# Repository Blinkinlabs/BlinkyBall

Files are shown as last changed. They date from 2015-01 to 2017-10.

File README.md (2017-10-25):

# Circuit and code for a heartbeat bouncy ball
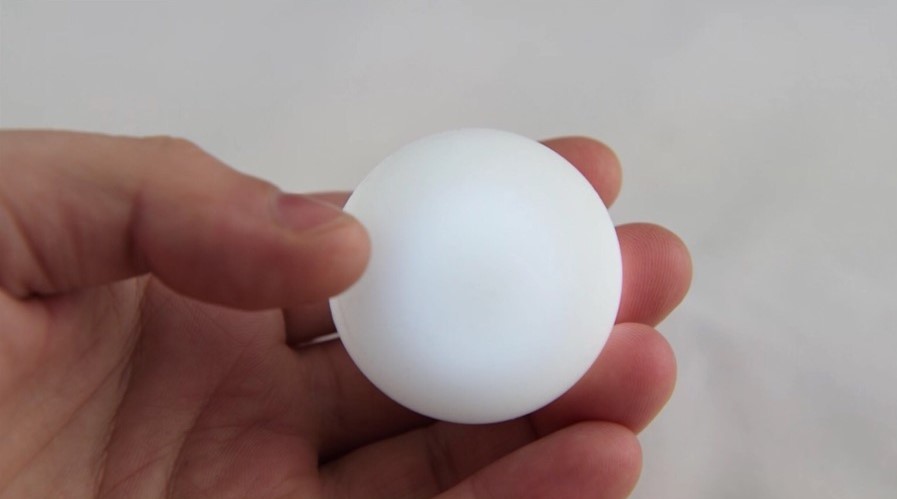
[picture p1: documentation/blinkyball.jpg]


## License

This design, including the software and hardware, is licensed under the MIT license.

## PCB Design

The PCB design is made in Cadsoft Eagle 7.1 (http://www.cadsoftusa.com/download-eagle/).
The free version should be fine for opening and editing the design.

It's based on the Atmel ATTINY85, though an ATTINY45 or ATTINY25 would probably also work.

## Firmware

The firmware is written against avr-gcc.

### Toolchain setup for OS X

Install XCode and command line tools. Version 6.1.1 was used for development, but this should
not be critical. The method for enabling the command line tools seems to be a moving target,
one set of instructions is here (https://developer.apple.com/library/ios/technotes/tn2339/_index.html).

Install CrossPack for AVR (http://www.obdev.at/products/crosspack/download.html). Version
CrossPack-AVR 20130212 was used for development. Most likey this code is not version-sensitive.

### Compiling

Once the toolchain is configured, this should be as simple as:

  make
  
### Uploading firmware

An AVR ISP is required to upload code. The Makefile is configured to use a USBTinyISP
(https://learn.adafruit.com/usbtinyisp), however it would be trivial to use a different
one, or even an Arduino to upload the code.

Solder the 6 ICSP test points on the board (use Eagle to inspect the pinout- the board design
is a moving target), then an automatic upload should work:

  make install

A test jig can also be built to make code upload possible without soldering.

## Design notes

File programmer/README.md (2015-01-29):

# Test Programmer for RasPi

This is a test system for Raspberry Pi. To use it, you'll first need to install avrdude:

	sudo apt-get install avrdude

Make sure that this repository is downloaded to /home/pi/BlinkyBall.

Then add it to init.d:

	cd ~pi/BlinkyBall
	cp programmer/blinkyball-programmer /etc/init.d
	update-rc.d blinkyball-programmer defaults	

# Pinout

This is the pinout for the board. Note that the pin numbers listed are Pi pins, not GPIO

Button should be connected from pin 3 to GND

LED anode to +3.3V
Red LED cathode to pin 22
Green LED cathode to pin 24
Blue LED cathode to pin 26

# Usage

Once the script is installed, it should start automatically at boot. Press the button to start the upload procedure. The light should turn blue while testing, then red if the upload failed or green if it passed.

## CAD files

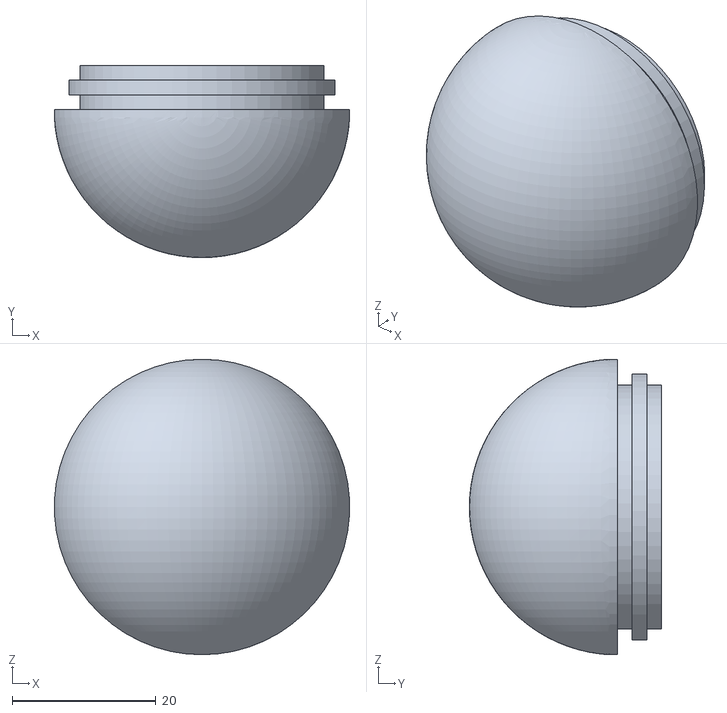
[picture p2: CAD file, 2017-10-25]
releases/case bottom.STL
41.1 x 26.8 x 41.1

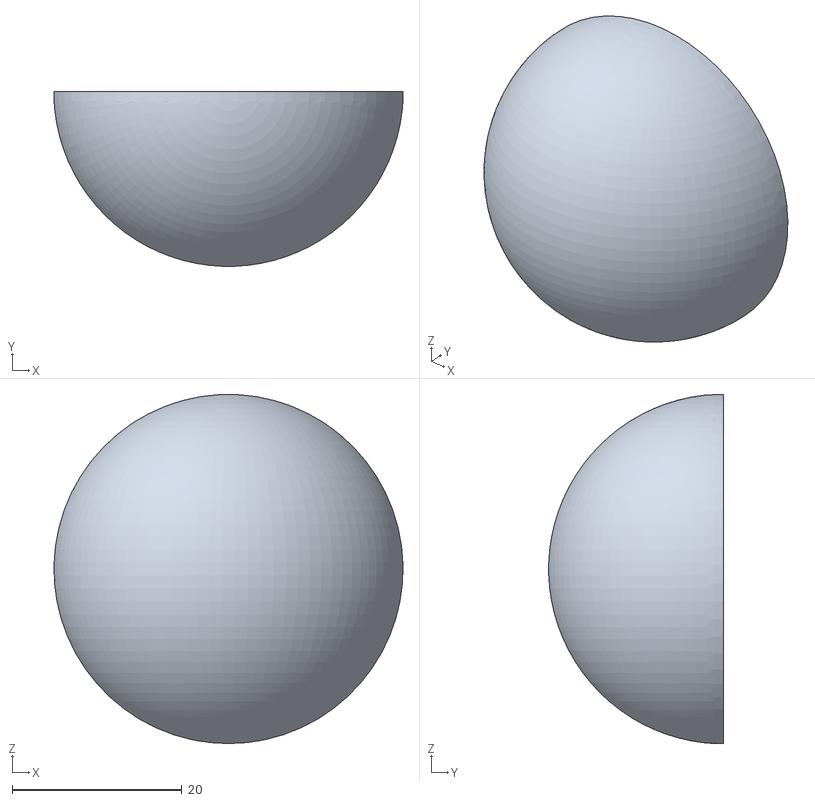
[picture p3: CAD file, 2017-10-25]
releases/case top.STL
41.1 x 20.6 x 41.1

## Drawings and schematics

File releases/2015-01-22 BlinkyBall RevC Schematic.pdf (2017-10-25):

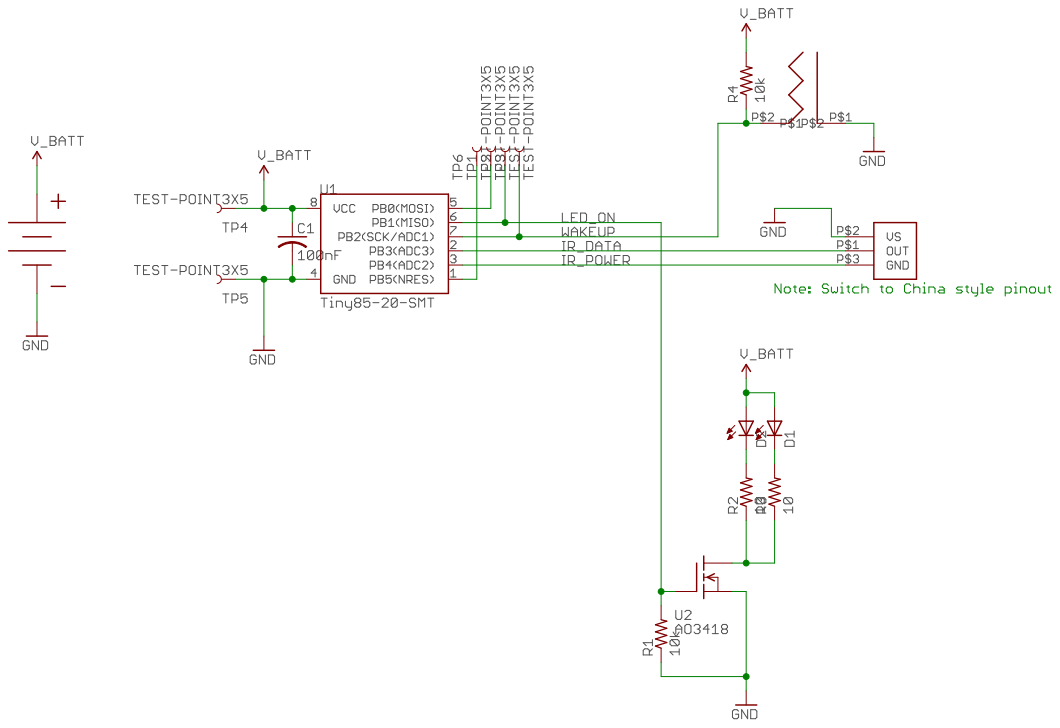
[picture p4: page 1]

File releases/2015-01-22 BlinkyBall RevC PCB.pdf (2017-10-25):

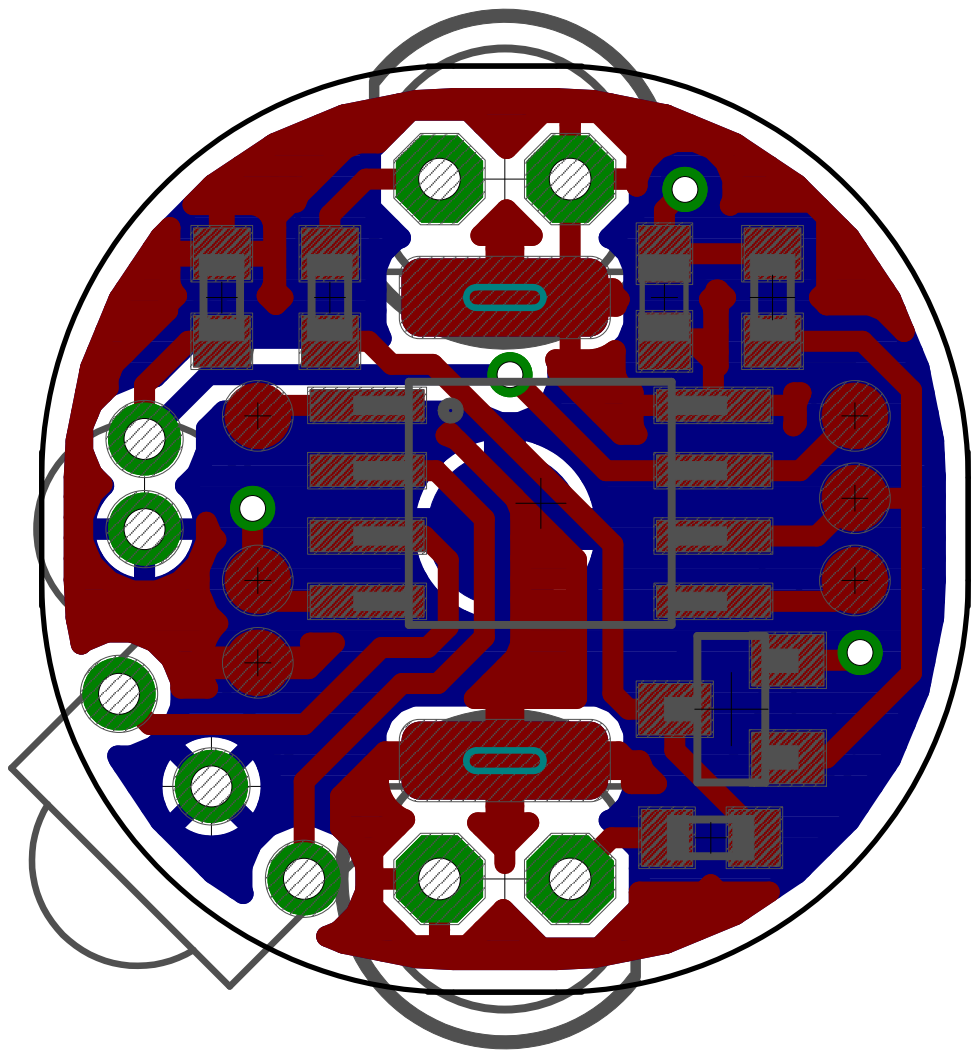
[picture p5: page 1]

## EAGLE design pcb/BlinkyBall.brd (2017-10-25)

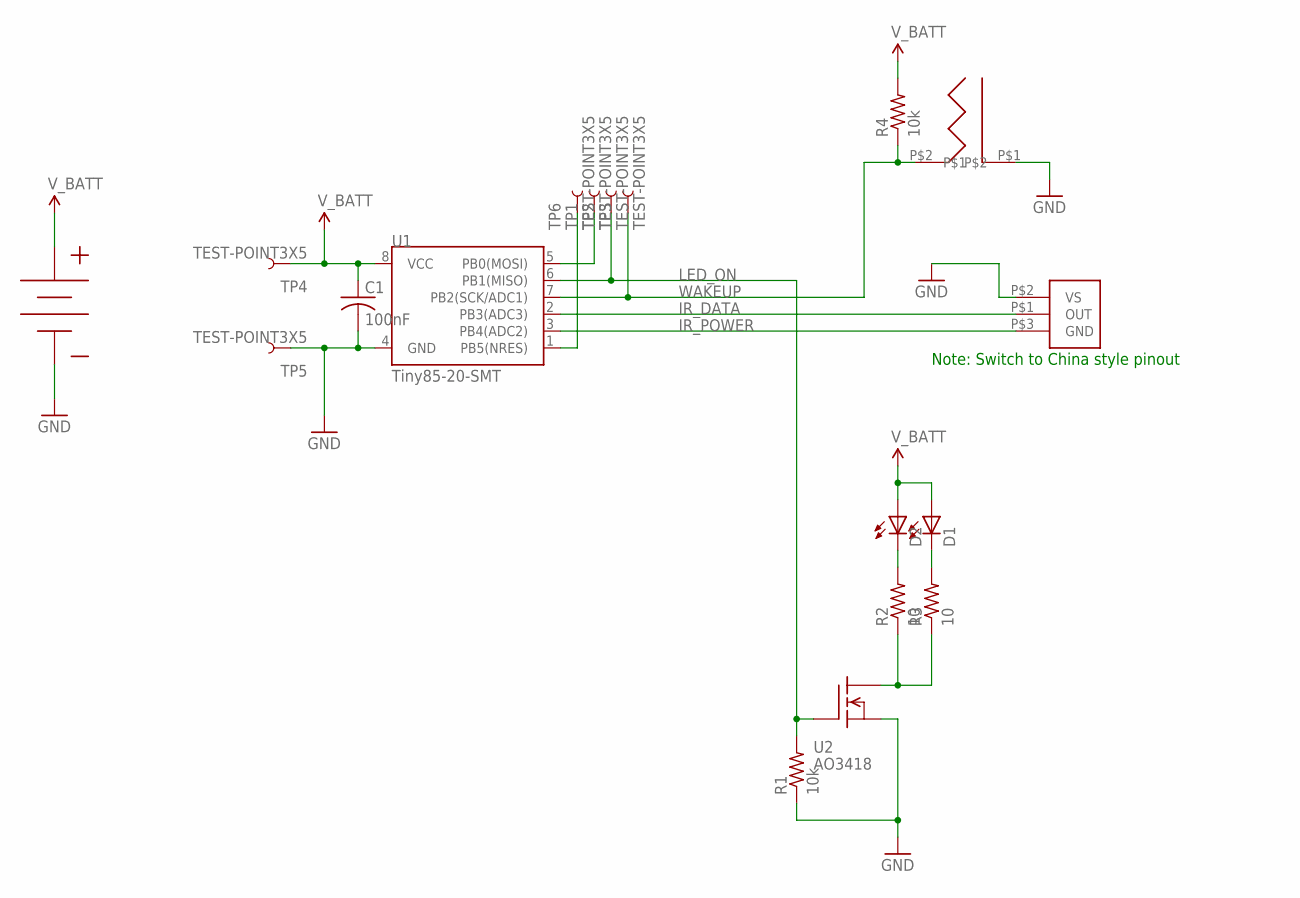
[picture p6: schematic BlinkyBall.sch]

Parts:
C1: 100nF; C0603
D1, D2: LED5MM
J1: SW-18015P
J2: BATTERY_BUTTON_CELLAG3; BATTERY_COVER_AG3
R1, R4: 10k; R0603
R2, R3: 10; R0603
TP1, TP2, TP3, TP4, TP5, TP6: TEST-POINT3X5; PAD.03X.05
U1: Tiny85-20-SMT; SO08-EIAJ
U2: AO3418; SOT23
U3: TSOP321

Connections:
GND: C1.2, J1.P$1, J2.-, R1.1, TP5.P$1, U1.4 (GND), U2.2 (S), U3.P$2 (VS)
IR_DATA: U1.2 (PB3(ADC3)), U3.P$1 (OUT)
IR_POWER: U1.3 (PB4(ADC2)), U3.P$3 (GND)
LED_ON: R1.2, TP2.P$1, U1.6 (PB1(MISO)), U2.1 (G)
unnamed: D2.K (C), R2.2
unnamed: D1.K (C), R3.2
unnamed: R2.1, R3.1, U2.3 (D)
RESET: TP6.P$1, U1.1 (PB5(NRES))
V_BATT: C1.1, D1.A, D2.A, J2.+1 (+), J2.+2 (+), J2.+3 (+), J2.+4 (+), R4.2, TP4.P$1, U1.8 (VCC)
WAKEUP: J1.P$2, R4.1, TP3.P$1, U1.7 (PB2(SCK/ADC1))
YYYYY: TP1.P$1, U1.5 (PB0(MOSI))

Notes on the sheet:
Note: Switch to China style pinout

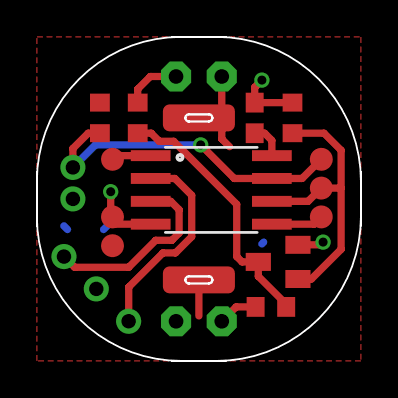
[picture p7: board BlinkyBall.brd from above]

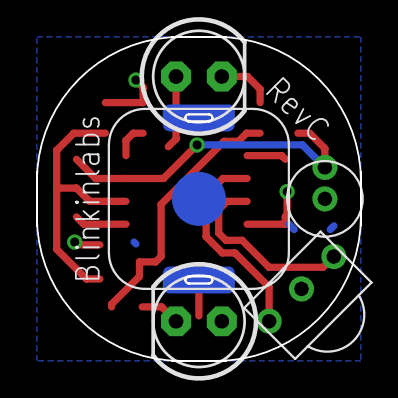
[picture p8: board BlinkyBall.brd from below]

Board: 2 copper layers, 18.0 x 18.0 mm, 18 parts (5 on the bottom side), 11 nets.

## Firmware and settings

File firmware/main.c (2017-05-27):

/* Name: main.c
 * Heartbeat ball
 *
 * Copyright 2015 Blinkinlabs, LLC
 * Author: Matt Mets
 *
 * Based loosely on the ATTiny example by Markus Konrad
 */

#include <avr/sleep.h>
#include <avr/interrupt.h>
#include <avr/io.h>
#include <avr/pgmspace.h>
#include <avr/eeprom.h>
#include <avr/wdt.h>
#include <util/delay.h>
#include "irremote.h"
#include "blinkyball.h"
#include "crc.h"
#include "seven_cycles_corrected.h"

// Bounce sensitivity, in interrupt counts. Increase to decrease sensitivity
volatile uint8_t debounceCount;

// Heartbeat speed, in 10ths of a millisecond per sample
// To convert from BPM to this constant, use the following formula:
// ((60/BPM/SAMPLES*7)) × 10000
// or : 8458/bpm
// where SAMPLES is equal to the heartbeat sample count for seven cycles (497)
// Examples:
// 60bpm: 140
// 150bpm: 56
volatile uint8_t heartbeatSpeed;

// Number of times the 7-beat pattern is repeated
volatile uint8_t repeatCount;

// Counter for interrupt-based debounce routine
volatile uint8_t interruptCount;

// IR Receiver 
extern decode_results_t results;

void sleep()
{
    interruptCount = 0;

    bitSet(GIMSK, INT0);    // Enable INT0

    sleep_enable(); // Sets the Sleep Enable bit in the MCUCR Register (SE BIT)
    sei(); // Enable interrupts
    sleep_cpu(); // SLEEP
 
    sleep_disable(); // Clear SE bit

    // Wait a small amount of time to accrue debounce information   
    _delay_ms(1);

    cli(); // Disable interrupts
    bitClear(GIMSK, INT0);      // Disable INT0
    sei(); // Enable interrupts
}

ISR(INT0_vect) {
    interruptCount++;
}

// Validate the configuration rates. Do this when they are loaded and when they are changed.
inline void validateRates() {
    if(repeatCount > REPEAT_COUNT_MAXIMUM) {
        repeatCount = REPEAT_COUNT_MAXIMUM;
    }
    if(repeatCount < REPEAT_COUNT_MINIMUM) {
        repeatCount = REPEAT_COUNT_MINIMUM;
    }

    if(debounceCount > DEBOUNCE_COUNT_MAXIMUM) {
        debounceCount = DEBOUNCE_COUNT_MAXIMUM;
    }
    if(debounceCount < DEBOUNCE_COUNT_MINIMUM) {
        debounceCount = DEBOUNCE_COUNT_MINIMUM;
    }

    if(heartbeatSpeed > HEARTBEAT_SPEED_MAXIMUM) {
        heartbeatSpeed = HEARTBEAT_SPEED_MAXIMUM;
    }
    if(heartbeatSpeed < HEARTBEAT_SPEED_MINIMUM) {
        heartbeatSpeed = HEARTBEAT_SPEED_MINIMUM;
    }
}

// Store the configuration rates in EEPROM
inline void saveRates() {
    eeprom_write_byte((uint8_t*)DEBOUNCE_COUNT_ADDRESS,   DEBOUNCE_COUNT_DEFAULT);
    eeprom_write_byte((uint8_t*)REPEAT_COUNT_ADDRESS,     REPEAT_COUNT_DEFAULT);
    eeprom_write_byte((uint8_t*)HEARTBEAT_SPEED_ADDRESS,  HEARTBEAT_SPEED_DEFAULT);
    eeprom_write_byte((uint8_t*)MAGIC_HEADER_ADDRESS,     MAGIC_HEADER_VALUE);
}

// Load the configuration rates from EEPROM, or create from default if they weren't
// already initialized
inline void loadRates() {
    // If the EEPROM wasn't initialized, do so now
    if(eeprom_read_byte((uint8_t*)MAGIC_HEADER_ADDRESS) != MAGIC_HEADER_VALUE) {
        debounceCount  = DEBOUNCE_COUNT_DEFAULT;
        repeatCount    = REPEAT_COUNT_DEFAULT;
        heartbeatSpeed = HEARTBEAT_SPEED_DEFAULT;
        saveRates();
    }

    debounceCount  = eeprom_read_byte((uint8_t*)DEBOUNCE_COUNT_ADDRESS);
    repeatCount    = eeprom_read_byte((uint8_t*)REPEAT_COUNT_ADDRESS);
    heartbeatSpeed = eeprom_read_byte((uint8_t*)HEARTBEAT_SPEED_ADDRESS);
}

// Play back one loop of the heartbeat signal
// Duration: nominal 7 seconds at 60 BPM
void playEKG() {
    uint8_t sample;

    for(uint16_t loop = 0; loop < repeatCount; loop++) {
        for(uint16_t position = 0; position < EKG_DATA_LENGTH; position++) {
            sample = pgm_read_byte(&ekgData[position]);

            setLEDs(sample);

            // make a delay based on the heartbeat speed
            for(uint16_t count = 0; count < heartbeatSpeed; count++) {
                _delay_us(100);
            }

            // And hit the watchdog
            wdt_reset();
        }
    }

    setLEDs(0);
}

// Listen for an IR command
// Duration: 4+ seconds
void monitorIR() {
    setLEDs(0); // Make sure that the LEDs are off to prevent interference
    enableIRIn(); // Start the receiver
    
    for(uint32_t irLoop = 0; irLoop < IR_MONITOR_TIME; irLoop++) {
    
        _delay_ms(60);  // Derate this to handle processing time of decodeIR() @4MHz

        wdt_reset(); // Hit the watchdog

        // If we didn't get an NEC command, bail
        if (!decodeIR()) {
            continue;
        }

        uint8_t speed =         (results.value >> 24) & 0xFF;
        uint8_t repeats =       (results.value >> 16) & 0xFF;
        uint8_t sensitivity =   (results.value >>  8) & 0xFF;

        resetCRC();
        updateCRC(speed);
        updateCRC(repeats);
        updateCRC(sensitivity);

        // If the CRC is valid, store the results.
        if(getCRC() == (results.value & 0xFF)) {
            // Update the rates both in working memory and in the EEPROM
            heartbeatSpeed = speed;
            repeatCount = repeats;
            debounceCount = sensitivity;
            validateRates();
            saveRates();

            // Flash the LEDs to indicate IR reception
            for(uint8_t i = 0; i < 5; i++) {
                setLEDs(i%2==0?20:0);
                _delay_ms(2);
            }
            setLEDs(0);

            // And reset our timeout counter
            irLoop = 0; 
        }
        
        resumeIR(); // Receive the next value
        
    }
}


// program entry point
// Kinda sad that the production devices will only run this once T_T
// Unless they brown out and somehow restart O_O
int main(void) {
    cli();
    MCUSR &= ~_BV(WDRF); // Clear the watchdog reset flag
    wdt_enable(WDTO_2S);
    wdt_reset();
    sei();

    // Change the clock to 4MHz
    __asm__ volatile (
        "st Z,%1" "\n\t"
        "st Z,%2"
        : :
        "z" (&CLKPR),
        "r" ((uint8_t) (1<<CLKPCE)),
        "r" ((uint8_t) 1)  // new CLKPR value 0=8MHz, 1=4MHz, 2=2MHz, 3=1MHz)
    );

    bitSet(DDRB,    PIN_LED_ON);
    bitSet(PORTB,   PIN_LED_ON);
    _delay_us(20);
    bitClear(PORTB, PIN_LED_ON);
    _delay_us(20);

    bitSet(ACSR, ACD);          // Disable the analog comparitor
    bitClear(ADCSRA, ADEN);     // Disable the ADC
    // Note: Brown out detection disabled by fuse setting
    // Note: Watchdog disabled by fuse setting

    // Disable clicks to peripherals that we aren't using
    // (This saves power in run mode)
    PRR |= _BV(PRUSI) | _BV(ADC);

    // Configure the sleep mode and wakeup interrupt
    MCUCR &= ~(_BV(ISC01) | _BV(ISC00));    // INT0 on low level
    set_sleep_mode(SLEEP_MODE_PWR_DOWN);    // Use power down mode for sleep

    // Set up timer1 to do PWM output to the LEDs (OC1A)
    OCR1C = 0xFF;
    TCCR1 = _BV(PWM1A) | _BV(COM1A1) | _BV(CS10);

    // Load configuration from EEPROM and validate it
    loadRates();
    validateRates();

    // Main loop. The first thing that we do is turn off peripherals that we don't need,
    // then we go to sleep. When woken up, run a quick debounce routine to determine if we
    // should go into LED display mode, and at the completion go back to sleep.
    for(;;){

        // Disable the IR timer
        disableIRIn();

        // Turn off the LED outputs before disabling the pins
        setLEDs(0);
        _delay_ms(1);

        // Set all I/O pins to input, and pull-up resistors for floating pins
        DDRB = 0;
        PORTB = _BV(PIN_UNUSED);

        // Disable the watchdog
        wdt_disable();

        // Go to sleep
        sleep();

        // Re-enable the watchdog
        wdt_enable(WDTO_2S);

        // Do a quick debounce check, to discard small shakes
        if(interruptCount < debounceCount) {
            continue;
        }

        // Set the LED pin as a output, and enable the IR receiver
        DDRB = _BV(PIN_LED_ON) | _BV(PIN_IR_POWER);
        PORTB = _BV(PIN_UNUSED) | _BV(PIN_IR_POWER);

        // First play the heartbeat pattern back
        playEKG();
        // Finally, monitor the IR input
        monitorIR();
    }
    
    return 0;   /* never reached */
}

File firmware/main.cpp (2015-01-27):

/* Name: main.c
 * Heartbeat ball
 *
 * Copyright 2015 Blinkinlabs, LLC
 * Author: Matt Mets
 *
 * Based loosely on the ATTiny example by Markus Konrad
 */

#include <avr/sleep.h>
#include <avr/interrupt.h>
#include <avr/io.h>
#include <avr/pgmspace.h>
#include <util/delay.h>
#include <avr/eeprom.h>
#include "ekg_data.h"
#include "irremote.h"
#include "blinkyball.h"
#include "crc.h"


// System parameters
#define DEBOUNCE_COUNT_DEFAULT 15
#define HEARTBEAT_REPS_DEFAULT 6
#define HEARTBEAT_SPEED_DEFAULT 200

// EEPROM data addresses
const uint8_t MAGIC_HEADER_ADDRESS    = 0;
const uint8_t DEBOUNCE_COUNT_ADDRESS  = 1;
const uint8_t HEARTBEAT_REPS_ADDRESS  = 2;
const uint8_t HEARTBEAT_SPEED_ADDRESS = 3;

// Magic header to determine if the EEPROM was written properly
const uint8_t MAGIC_HEADER_VALUE = 0xDE;


// Bounce sensitivity, in interrupt counts. Increase to decrease sensitivity
volatile uint8_t debounceCount;

// Number of heartbeats played during each on-time
volatile uint8_t heartbeatReps;

// Heartbeat speed, in 10ths of a microsecond per sample
// To convert from BPM to this constant, use the following formula:
// ((60/BPM/SAMPLES)) × 100000
// where SAMPLES is equal to the heartbeat sample count (500)
// Examples:
// 60bpm: 200
// 100bpm: 120
volatile uint8_t heartbeatSpeed;

// Counter for interrupt-based debounce routine
volatile uint8_t interruptCount;

// IR Receiver 
IRrecv irrecv;
decode_results results;


void sleep()
{
    interruptCount = 0;

    bitSet(GIMSK, INT0);    // Enable INT0

    sleep_enable(); // Sets the Sleep Enable bit in the MCUCR Register (SE BIT)
    sei(); // Enable interrupts
    sleep_cpu(); // SLEEP
 
    sleep_disable(); // Clear SE bit

    // Wait a small amount of time to accrue debounce information   
    _delay_ms(1);

    cli(); // Disable interrupts
    bitClear(GIMSK, INT0);      // Disable INT0
    sei(); // Enable interrupts
}

ISR(INT0_vect) {
    interruptCount++;
}

inline void setLEDs(uint8_t value) {
    OCR1A = value;
}

// Store the configuration rates in EEPROM
inline void saveRates() {
    eeprom_write_byte((uint8_t*)DEBOUNCE_COUNT_ADDRESS,   DEBOUNCE_COUNT_DEFAULT);
    eeprom_write_byte((uint8_t*)HEARTBEAT_REPS_ADDRESS,   HEARTBEAT_REPS_DEFAULT);
    eeprom_write_byte((uint8_t*)HEARTBEAT_SPEED_ADDRESS,  HEARTBEAT_SPEED_DEFAULT);
    eeprom_write_byte((uint8_t*)MAGIC_HEADER_ADDRESS,     MAGIC_HEADER_VALUE);
}

// Load the configuration rates from EEPROM, or create from default if they weren't
// already initialized
inline void loadRates() {
    // If the EEPROM wasn't initialized, do so now
    if(eeprom_read_byte((uint8_t*)MAGIC_HEADER_ADDRESS) != MAGIC_HEADER_VALUE) {
        debounceCount = DEBOUNCE_COUNT_DEFAULT;
        heartbeatReps = HEARTBEAT_REPS_DEFAULT;
        heartbeatSpeed = HEARTBEAT_SPEED_DEFAULT;
        saveRates();
    }

    debounceCount =  eeprom_read_byte((uint8_t*)DEBOUNCE_COUNT_ADDRESS);
    heartbeatReps =  eeprom_read_byte((uint8_t*)HEARTBEAT_REPS_ADDRESS);
    heartbeatSpeed = eeprom_read_byte((uint8_t*)HEARTBEAT_SPEED_ADDRESS);
}

// Play back one loop of the heartbeat signal
inline void playEKG() {
    uint8_t position = 0;
    uint8_t count = 0;

    for(position = 0; position < EKG_DATA_LENGTH; position++) {
        setLEDs(pgm_read_byte(&ekgData[position]));

        // make a delay
        // Note that the system is heavily loaded by the IR sensor,
        // so this number has to be tuned.
        for(count = 0; count < heartbeatSpeed; count++) {
            _delay_us(8);  // Allow 1uS for loop setup
        }
    }
}

// Meausre the battery voltage under load
// @return Battery voltage, in counts (255=5V, 127=2.5V, etc)
inline uint8_t measureBattery() {
    // Select Vcc as voltage reference, Vbg as input, and left-justify result
    ADMUX = _BV(ADLAR) | _BV(MUX3) | _BV(MUX2);

    // Turn on the ADC, disable interrupts, and set the prescaler to /32
    ADCSRA = _BV(ADEN) | _BV(ADPS2);
   
    // Turn on the LEDs
    setLEDs(255);

    // Wait 1ms as per the datasheet recommendation before sampling Vbg
    _delay_ms(1);

    // Trigger a conversion
    ADCSRA |= _BV(ADSC);

    // Wait for conversion to finish
    while(ADCSRA & _BV(ADSC)) {}

    // Turn off the LEDs
    setLEDs(0);

    // Sample ADCH
    uint8_t measured = ADCH;

    // Disable ADC
    ADCSRA = 0;

    // The measured value is equal to:
    // measured = Vbg/Vcc*counts
    // so Vcc = Vbg*counts/measured
    // to put it in counts (0-255), multiply by 255/5V:
    // Vcc = Vbg*counts/measured*255/5
    // Vbg is 1.1V nominally, so this can be reduced to:
    // 14305 / measured
    return 14305 / measured;
}

// program entry point
// Kinda sad that the production devices will only run this once T_T
int main(void) {

    // Change the clock to 8MHz
    asm volatile (
        "st Z,%1" "\n\t"
        "st Z,%2"
        : :
        "z" (&CLKPR),
        "r" ((uint8_t) (1<<CLKPCE)),
        "r" ((uint8_t) 0)  // new CLKPR value 0=8MHz, 1=4MHz, 2=2MHz, 3=1MHz)
    );

    bitSet(ACSR, ACD);          // Disable the analog comparitor
    bitClear(ADCSRA, ADEN);     // Disable the ADC
    // Note: Brown out detection disabled by fuse setting
    // Note: Watchdog disabled by fuse setting

    // Disable clicks to peripherals that we aren't using
    // (This saves power in run mode)
    PRR |= _BV(PRUSI);

    // Configure the sleep mode and wakeup interrupt
    MCUCR &= ~(_BV(ISC01) | _BV(ISC00));    // INT0 on low level
    set_sleep_mode(SLEEP_MODE_PWR_DOWN);    // Use power down mode for sleep

    // Set up timer1 to do PWM output to the LEDs (OC1A)
    OCR1C = 0xFF;
    TCCR1 = _BV(PWM1A) | _BV(COM1A1) | _BV(CS10);

    loadRates();

    // Main loop. The first thing that we do is turn off peripherals that we don't need,
    // then we go to sleep. When woken up, run a quick debounce routine to determine if we
    // should go into LED display mode, at at the completion go back to sleep.
    for(;;){
        // Disable the IR timer
        irrecv.disableIRIn();

        // Turn off the LED outputs before disabling the pins
        setLEDs(0);
        _delay_ms(1);

        // Set all I/O pins to input, and pull-up resistors for floating pins
        DDRB = 0;
        PORTB = _BV(PIN_UNUSED);

#if 1
        // Go to sleep
        sleep();

        // Do a quick debounce check, to discard small shakes
        if(interruptCount < debounceCount) {
            continue;
        }
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

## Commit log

2015-01-17 RevA board design
    [BlinkyBall.brd, BlinkyBall.sch]
2015-01-17 Working towards RevB board design: Smaller, more vertical
    [BlinkyBall.brd, BlinkyBall.sch]
2015-01-17 Add real-life EKG pulse
    [ekg-example.csv]
2015-01-19 RevB pcb- transistor switch for LEDs
    [BlinkyBall.brd, BlinkyBall.sch]
2015-01-19 Add switched-cap design for potential power boost
    [BlinkyBall-switchedcap.brd, BlinkyBall-switchedcap.sch]
2015-01-19 Display solid pattern for LED evaluation
2015-01-19 Move PCB designs to their own directory
    [BlinkyBall-switchedcap.brd, BlinkyBall-switchedcap.sch, BlinkyBall.brd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]
2015-01-22 Switch to c++ compiler, use timer1 for LED PWM
2015-01-22 RevC pcb design: rounded rect, switch IR pinout, space out test points
    [BlinkyBall-switchedcap.brd, BlinkyBall-switchedcap.sch, BlinkyBall.brd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]
2015-01-22 More design tweaks
    [BlinkyBall.brd, BlinkyBall.sch]
2015-01-22 RevC, as submitted for production
    [BlinkyBall.brd]
2015-01-26 PCB: Fix referene names
    [BlinkyBall.brd, BlinkyBall.sch]
2015-01-26 Correct pinout for IR receiver
    [BlinkyBall.brd, BlinkyBall.sch]
2015-01-27 Tighten up timing requirements
    [irremoteint.h]
2015-01-27 Intersperse IR readings with LED output
2015-01-27 Push LED frequency back to 32KHz
2015-01-27 Bugfix: used too much RAM
    [main.cpp]
2015-01-27 IR works: ran out of memory, so disable interrupts during intensive operations
2015-01-27 Add arduino programmer example
2015-01-27 Add blink simulator for Arduino Uno
2015-01-27 Less bright LEDs for IR reception conformation
2015-01-28 Separate clock speeds for programming fuses, to work with fresh chips
2015-01-28 Switch to C for much lower processing demands
2015-01-28 Use 7 flashes pattern
    [seven_cycles.csv]
2015-01-29 Improve voltage scaling design
2015-01-29 Adjust timings, disable voltage scaling (boo!)
2015-01-30 Change sensitivity to 100 in arduino program, and add verify function to Makefile
2015-01-30 Update fuse setting
2017-05-27 Fixes for case-sensitive file system
    [irremote.c, irremoteint.h, main.c]
2017-10-25 Remove old schematic design, add release files for production version
    [BlinkyBall-switchedcap.brd, BlinkyBall-switchedcap.sch, BlinkyBall.brd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]

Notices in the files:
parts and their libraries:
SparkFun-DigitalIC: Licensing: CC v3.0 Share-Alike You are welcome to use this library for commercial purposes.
